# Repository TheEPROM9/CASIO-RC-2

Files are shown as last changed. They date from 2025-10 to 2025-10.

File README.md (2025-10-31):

# CASIO-RC-2
This RAM pack is for the CASIO FX-720P or similar pocket computer. This unit is 2KB 4-BIT memory with battery backup that is user removable. The RAM pack also came in 4KB variants, I do not have one of these yet. This will be an open source project as mod & contribute as you desire.

I have now uploaded the full schmatic & PCB files. As usual they are currently untesdted to feel free to contribute.

Link to project: [CASIO RC-2 RAM Pack](https://www.theeprom9.co.uk/vintage-computers/reverse-engineering-computers/casio-rc-2-ram-pack)

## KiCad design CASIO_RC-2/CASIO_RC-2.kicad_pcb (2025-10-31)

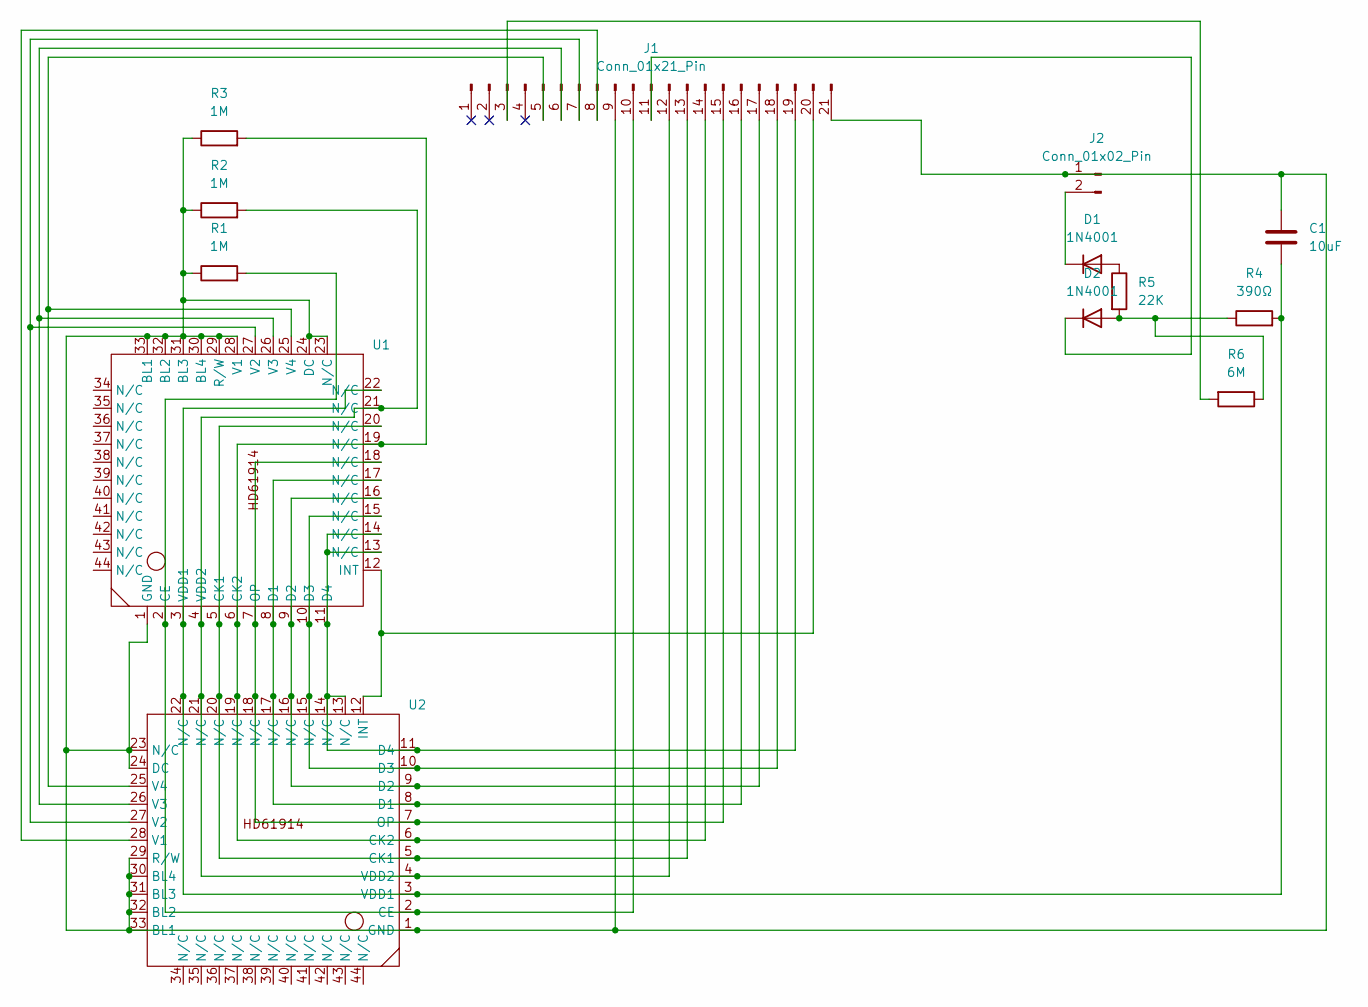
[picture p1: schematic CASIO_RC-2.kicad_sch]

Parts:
C1: 10uF; C_1808_4520Metric
D1, D2: 1N4001; D_1206_3216Metric
J1: Conn_01x21_Pin; CASIO_RC-2_RAM_Pinheadder
J2: Conn_01x02_Pin; CR2023_Battery_Terminal
R1, R2, R3: 1M; R_1206_3216Metric
R4: 390Ω; R_1206_3216Metric
R5: 22K; R_1206_3216Metric
R6: 6M; R_1206_3216Metric
U1, U2: HD61914

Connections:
unnamed: D1.2 (A), R5.1
unnamed: D1.1 (K), J2.2
unnamed: D2.2 (A), R4.1, R5.2, R6.1
unnamed: D2.1 (K), J1.11
unnamed: J1.3, R6.2
unnamed: J1.5, U1.25 (V4), U2.25 (V4)
unnamed: J1.6, U1.26 (V3), U2.26 (V3)
unnamed: J1.7, U1.27 (V2), U2.27 (V2)
unnamed: J1.8, U2.28 (V1)
unnamed: J1.10, R1.2, U1.2 (CE), U2.2 (CE)
unnamed: J1.12, R2.2, U1.4 (VDD2), U1.21 (N/C), U2.4 (VDD2), U2.21 (N/C)
unnamed: J1.13, U1.5 (CK1), U1.20 (N/C), U2.5 (CK1), U2.20 (N/C)
unnamed: J1.14, R3.2, U1.6 (CK2), U1.19 (N/C), U2.6 (CK2), U2.19 (N/C)
unnamed: J1.15, U1.7 (OP), U1.18 (N/C), U2.7 (OP), U2.18 (N/C)
unnamed: J1.16, U1.8 (D1), U1.17 (N/C), U2.8 (D1), U2.17 (N/C)
unnamed: J1.17, U1.9 (D2), U1.16 (N/C), U2.9 (D2), U2.16 (N/C)
unnamed: J1.18, U1.10 (D3), U1.15 (N/C), U2.10 (D3), U2.15 (N/C)
unnamed: J1.19, U1.11 (D4), U1.13 (N/C), U1.14 (N/C), U2.11 (D4), U2.13 (N/C), U2.14 (N/C)
unnamed: J1.20, U1.12 (INT), U2.12 (INT)
unnamed: C1.1, J1.9, J1.21, J2.1, R1.1, R2.1, R3.1, U1.1 (GND), U1.23 (N/C), U1.24 (DC), U1.28 (V1), U1.29 (R/W), U1.30 (BL4), U1.31 (BL3), U1.32 (BL2), U1.33 (BL1), U2.1 (GND), U2.23 (N/C), U2.24 (DC), U2.29 (R/W), U2.30 (BL4), U2.31 (BL3), U2.32 (BL2), U2.33 (BL1)
unnamed: C1.2, R4.2, U1.3 (VDD1), U1.22 (N/C), U2.3 (VDD1), U2.22 (N/C)

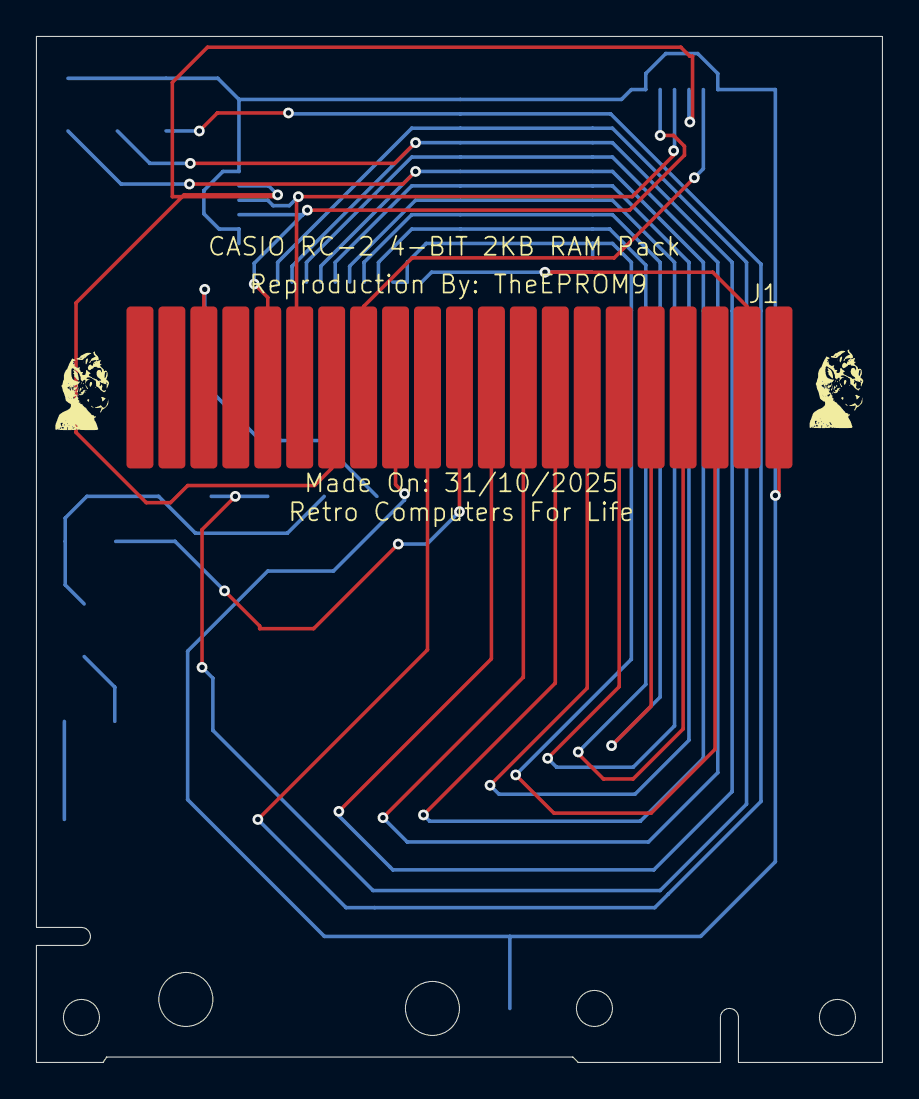
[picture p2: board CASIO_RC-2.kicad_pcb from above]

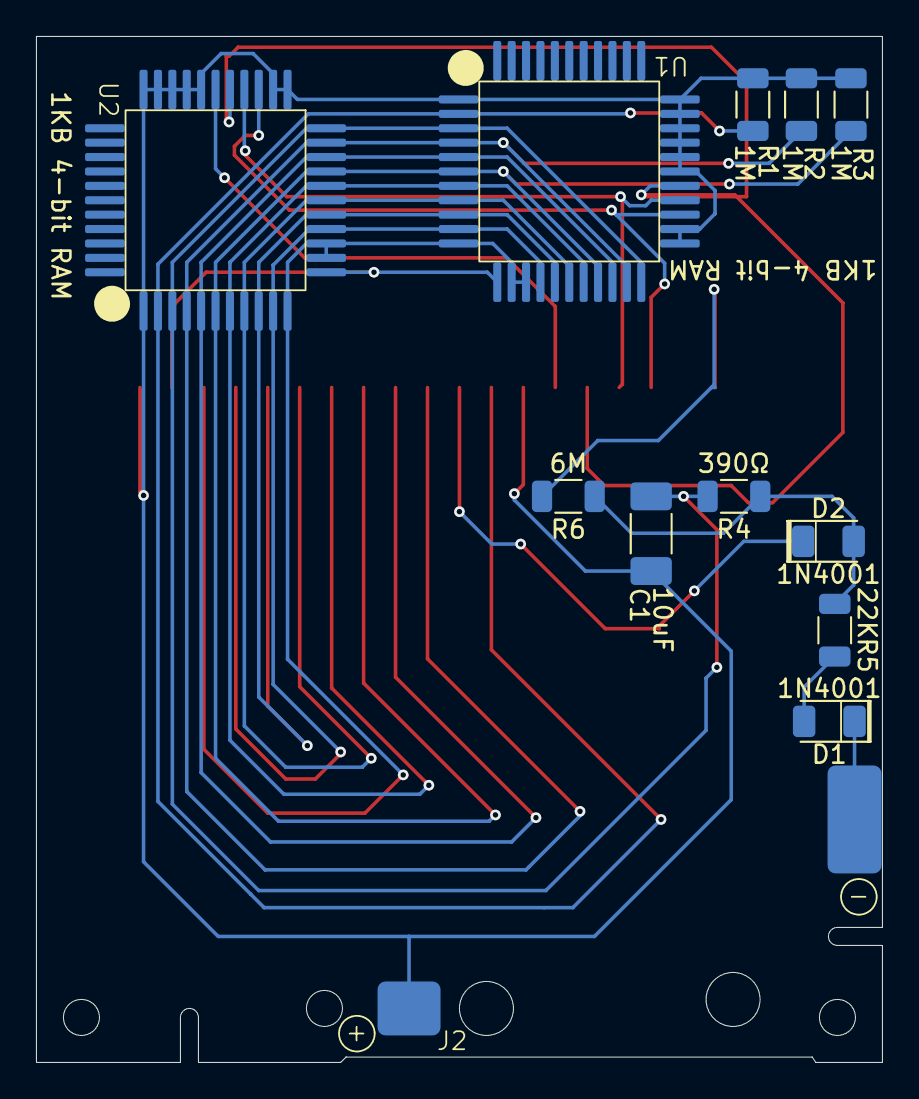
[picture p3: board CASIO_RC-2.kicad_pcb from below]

Board: 2 copper layers, 47.0 x 57.0 mm, 13 parts (12 on the bottom side), 21 nets.

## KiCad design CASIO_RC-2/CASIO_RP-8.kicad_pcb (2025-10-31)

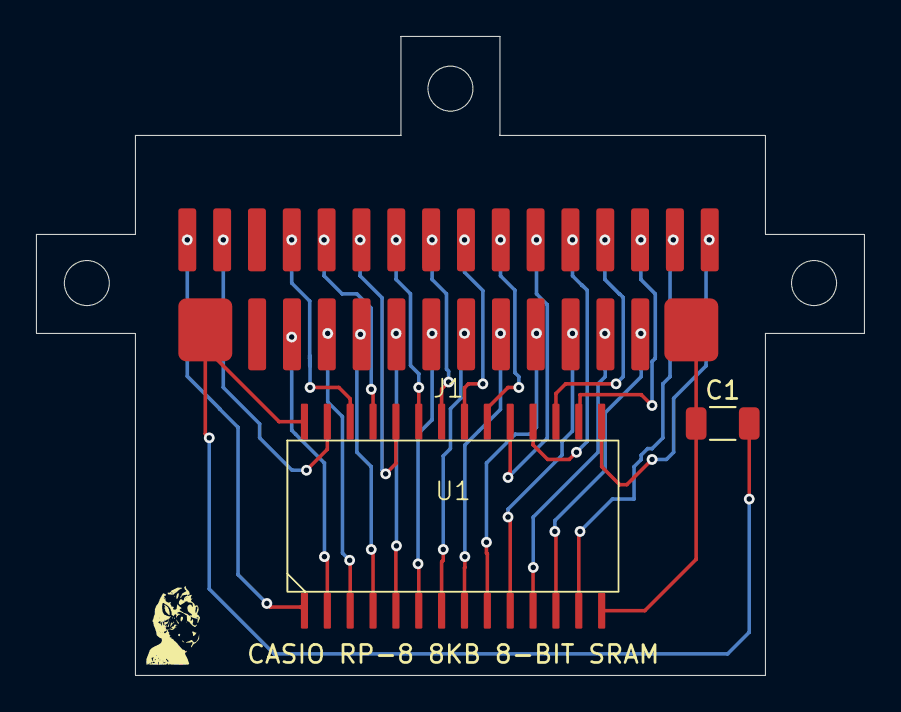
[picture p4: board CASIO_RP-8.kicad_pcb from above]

Board: 2 copper layers, 46.0 x 35.5 mm, 3 parts (0 on the bottom side), 28 nets.

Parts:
C1: 10uF; C_1206_3216Metric
J1: CASIO_RP-8_16_Pin_Headder
U1: LC3564PML

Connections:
unnamed: J1.27, U1.10 (A0)
unnamed: J1.26, U1.9 (A1)
unnamed: J1.25, U1.8 (A2)
unnamed: J1.24, U1.7 (A3)
unnamed: J1.23, U1.6 (A4)
unnamed: J1.22, U1.5 (A5)
unnamed: J1.21, U1.4 (A6)
unnamed: J1.20, U1.3 (A7)
unnamed: J1.5, U1.25 (A8)
unnamed: J1.6, U1.24 (A9)
unnamed: J1.9, U1.21 (A10)
unnamed: J1.7, U1.23 (A11)
unnamed: J1.19, U1.2 (A12)
unnamed: J1.10, U1.20 (CE1)
unnamed: J1.4, U1.26 (CE2)
unnamed: C1.1, J1.30, U1.14 (GND)
unnamed: J1.28, U1.11 (I/O1)
unnamed: J1.29, U1.12 (I/O2)
unnamed: J1.15, U1.13 (I/O3)
unnamed: J1.16, U1.15 (I/O4)
unnamed: J1.14, U1.16 (I/O5)
unnamed: J1.13, U1.17 (I/O6)
unnamed: J1.12, U1.18 (I/O7)
unnamed: J1.11, U1.19 (I/O8)
unnamed: J1.1, U1.1 (NO)
unnamed: J1.8, U1.22 (OE)
unnamed: C1.2, J1.17, U1.28 (VCC)
unnamed: J1.2, U1.27 (WE)

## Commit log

2025-10-20 First Upload Of Completed Schematic
    [CASIO_RC-2.kicad_pcb, CASIO_RC-2.kicad_sch]
2025-10-31 Fix Error With Schematic & Designed PCB
    An error with the schematic where the 6M resistor connected to the wrong side of the diode. I have also finally got round to designing the PCB after a ton of delays due to Migraine's & work burnout.
    [CASIO_RP-8.kicad_pcb, CASIO_RP-8.kicad_sch]
2025-10-31 Custom Footprints Uploaded
2025-10-31 Updated PCB
    Added all the little PCB details & fixed the hold spacing.
    [CASIO_RC-2.kicad_pcb]
